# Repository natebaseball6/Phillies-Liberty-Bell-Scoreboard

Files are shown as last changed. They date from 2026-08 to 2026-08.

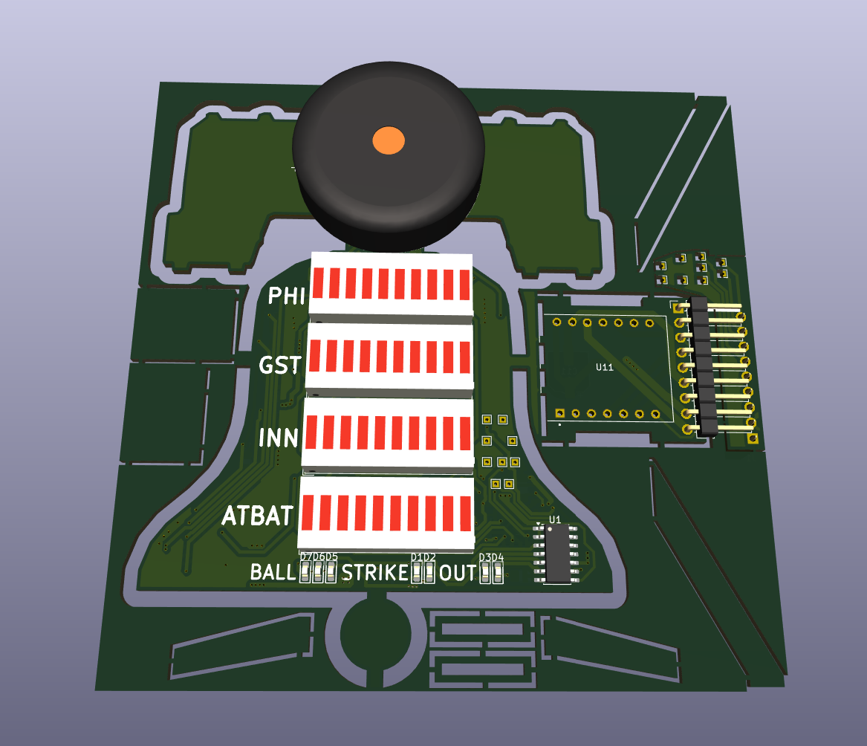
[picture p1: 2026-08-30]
Design Pictures/Screenshot 2026-08-30 145730.png

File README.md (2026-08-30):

# Phillies-Liberty-Bell-Scoreboard

Description: 

This project is intended to act as a desk toy resembling the Citizens' Bank Park Liberty Bell that "rings" whenever the Phillies hit a home run or win a game. The "bell" will feature a scoreboard on the front that accurately displays the live score, count, outs, inning, and more of a game.

The entire construction will be comprised of circuit board to minimize cost, as many small scale services such as JLC-PCB offer a fixed price for certain sizes of board, even if they are cut to smaller or more unique shapes. The shape of the bell will be one large circuit board, and the stand that holds it up will be a combination of smaller ones. 

The circuit will be ESP32 based, and overall very rudimentary and simple. Seven segment displays, individual LEDs, and a buzzer will be addressed by this ESP32.

The ESP32 will be connected to the local Wi-Fi network, and will fetch data from the MLB API for live scores.

Current Progress:

Brainstorming: DONE

Schematic Design (KiCAD): DONE

PCB Design (KiCAD): DONE

Physical Construction (JLCPCB + Digi Key): INCOMPLETE

Initial Test: INCOMPLETE

Programming: INCOMPLETE

API Test: INCOMPLETE

Polishing/Completion: INCOMPLETE

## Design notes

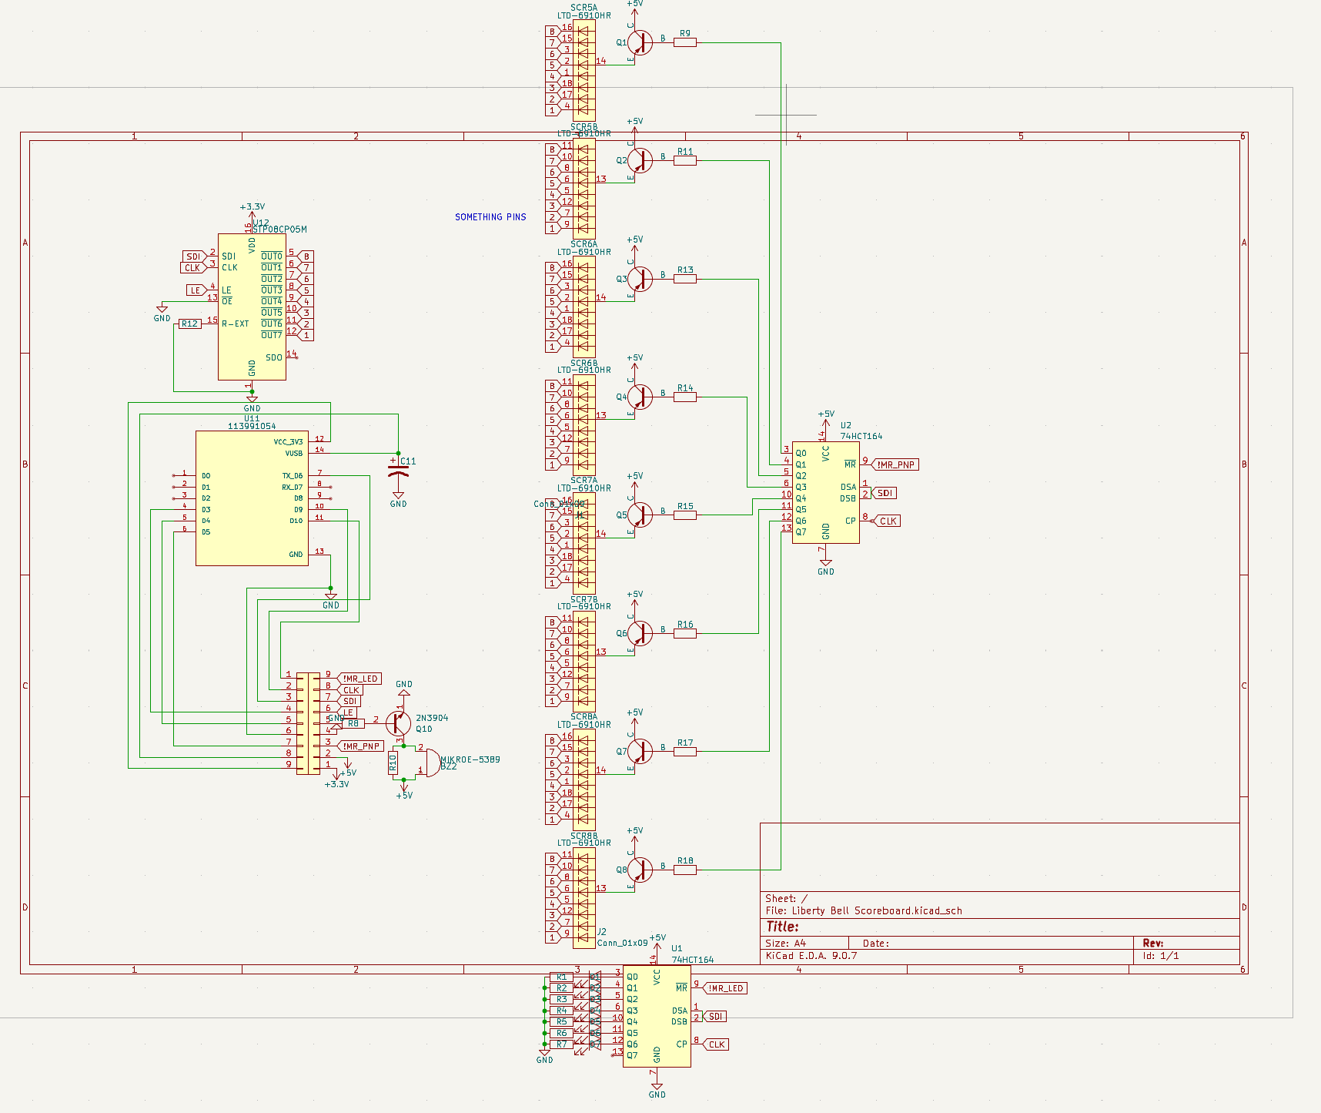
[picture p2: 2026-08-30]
Design Pictures/Screenshot 2026-08-30 145603.png

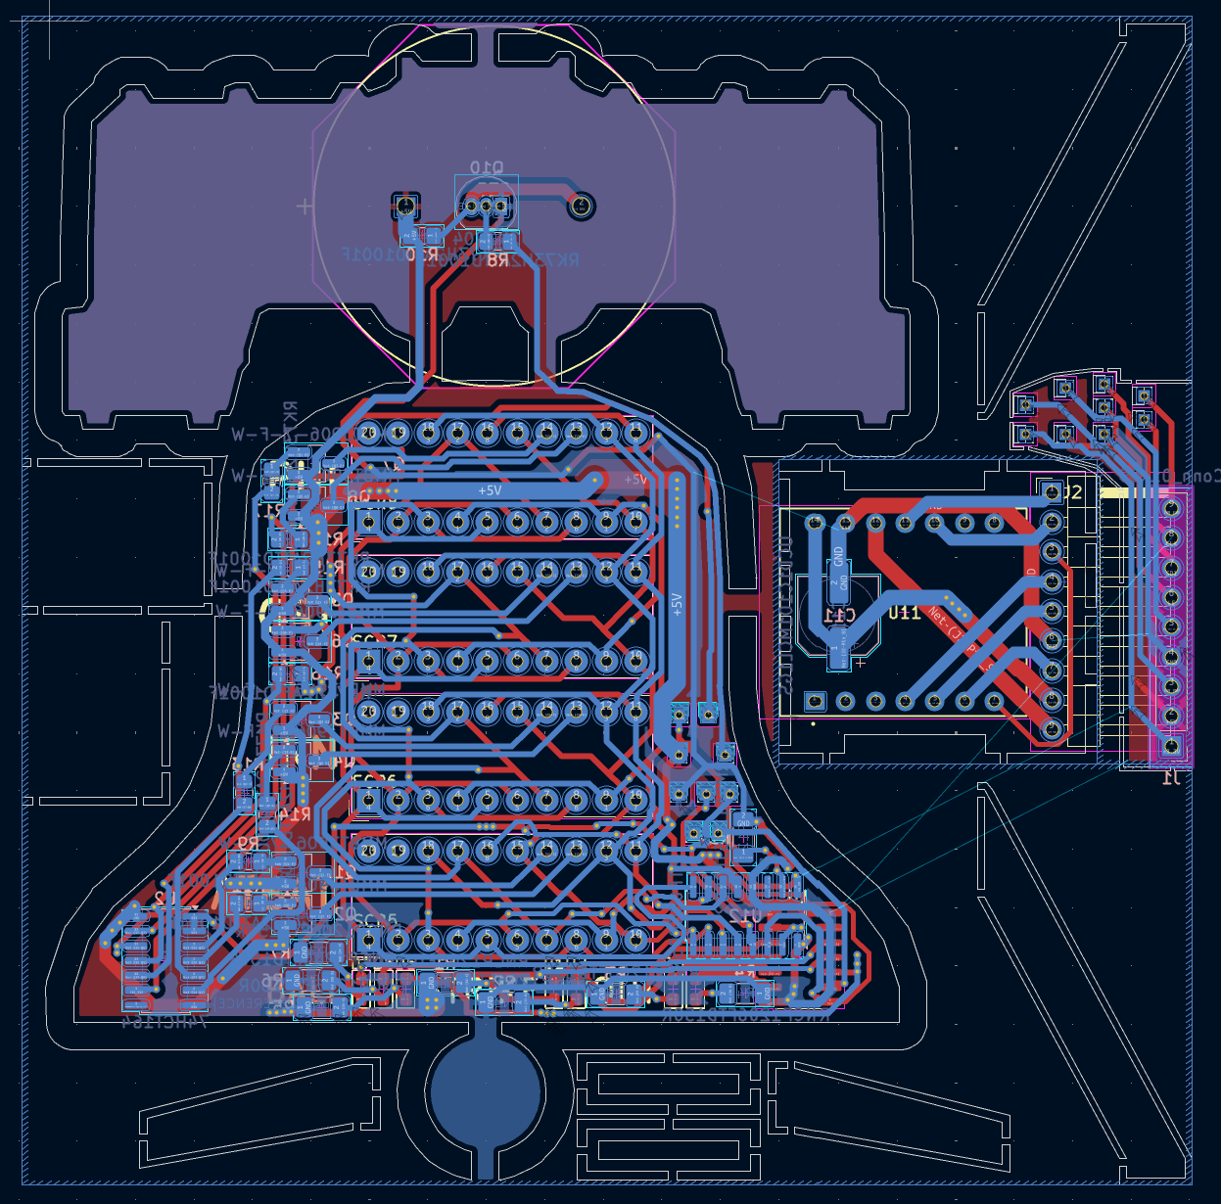
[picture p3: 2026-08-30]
Design Pictures/Screenshot 2026-08-30 145659.png

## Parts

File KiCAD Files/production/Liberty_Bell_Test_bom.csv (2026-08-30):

Designator | Footprint | Quantity | Value | LCSC Part #
BZ2 | LS_CT30P_CGE | 1 | MIKROE-5389
C11 | CP_Elec_6.3x5.9 | 1 | UCD1C101MCL1GS
D1, D2, D3, D4, D5, D6, D7 | 0603 | 7 | SML-D12U1WT86
J1 | PinSocket_1x09_P2.54mm_Vertical | 1 | Conn_01x09
J2 | PinHeader_1x09_P2.54mm_Horizontal | 1 | Conn_01x09
Q1, Q2, Q3, Q4, Q5, Q6, Q7, Q8 | SOT-23_Handsoldering | 8 | MMBT3906-7-F-W
Q10 | TO-92_Inline | 1 | 2N3904
R1, R2, R3, R4, R5, R6, R7 | 1206 | 7 | RNCP1206FTD150R
R10, R11, R13, R14, R15, R16, R17, R18, R8, R9 | 0805 | 10 | RK73H2ATTD1001F
R12 | 1206 | 1 | RMCF1206JT240R
SCR5, SCR6, SCR7, SCR8 | HDSP-4830 | 4 | LTD-6910HR
U1, U2 | SOIC-14_3.9x8.7mm_P1.27mm | 2 | 74HCT164
U11 | MODULE_113991054 | 1 | 113991054
U12 | SOIC-16_3.9x9.9mm_P1.27mm | 1 | STP08CP05M

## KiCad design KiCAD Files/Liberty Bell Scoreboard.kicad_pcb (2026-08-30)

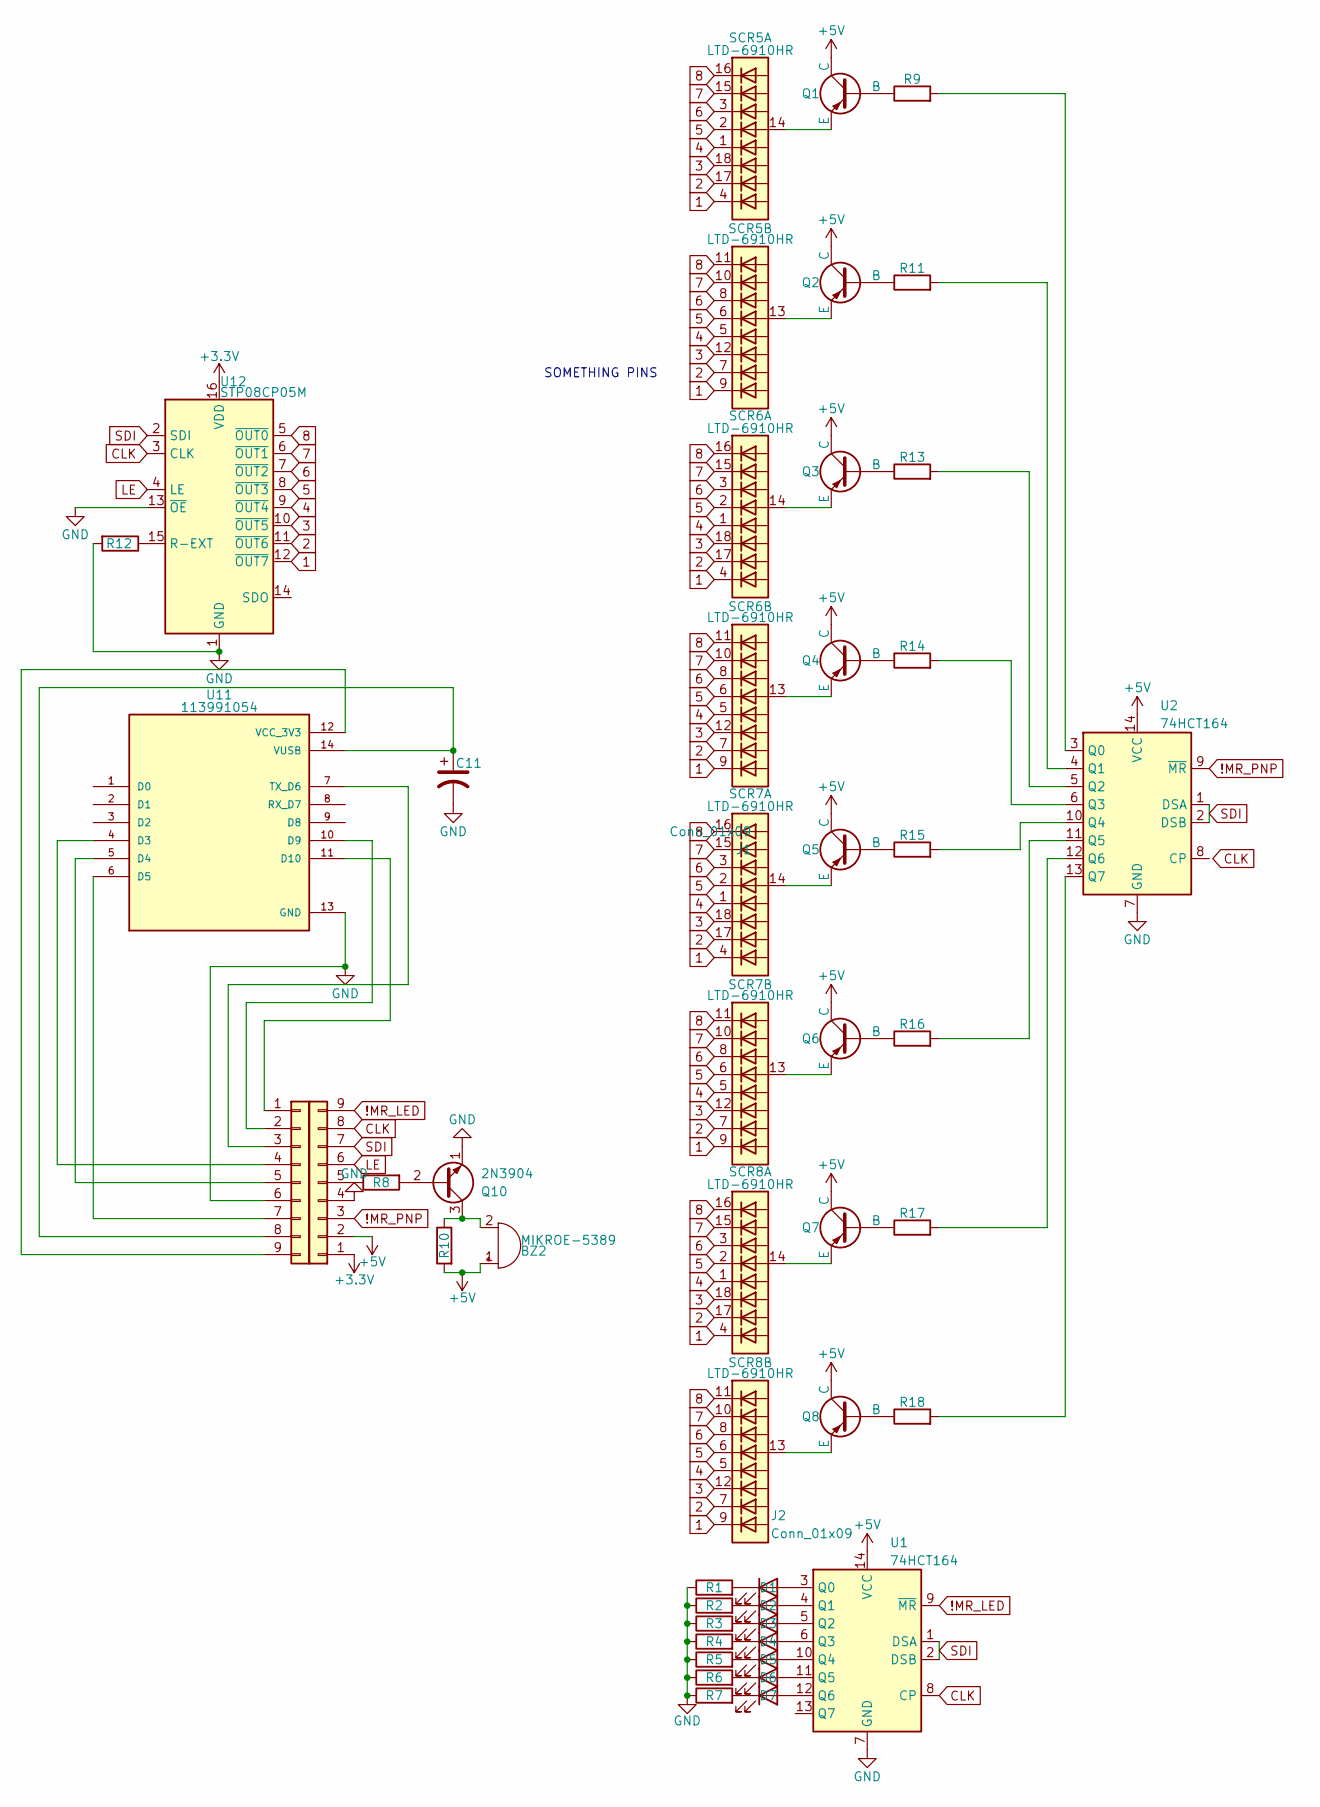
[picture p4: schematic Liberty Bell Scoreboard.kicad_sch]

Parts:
BZ2: MIKROE-5389; LS_CT30P_CGE
C11: UCD1C101MCL1GS; CP_Elec_6.3x5.9
D1, D2, D3, D4, D5, D6, D7: SML-D12U1WT86; LED_0603_1608Metric_Pad1.05x0.95mm_HandSolder
J1: Conn_01x09; PinSocket_1x09_P2.54mm_Vertical
J2: Conn_01x09; PinHeader_1x09_P2.54mm_Horizontal
Q1, Q2, Q3, Q4, Q5, Q6, Q7, Q8: MMBT3906-7-F-W; SOT-23_Handsoldering
Q10: 2N3904; TO-92_Inline
R1, R2, R3, R4, R5, R6, R7: RNCP1206FTD150R; R_1206_3216Metric_Pad1.30x1.75mm_HandSolder
R8, R9, R10, R11, R13, R14, R15, R16, R17, R18: RK73H2ATTD1001F; R_0805_2012Metric_Pad1.20x1.40mm_HandSolder
R12: RMCF1206JT240R; R_1206_3216Metric_Pad1.30x1.75mm_HandSolder
SCR5, SCR6, SCR7, SCR8: LTD-6910HR; HDSP-4830
U1, U2: 74HCT164; SOIC-14_3.9x8.7mm_P1.27mm
U11: 113991054; MODULE_113991054; PARTREV 23/05/2022; DigiKey_Part_Number 1597-113991054-ND
U12: STP08CP05M; SOIC-16_3.9x9.9mm_P1.27mm

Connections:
1: SCR5.4 (A), SCR5.9 (A), SCR6.4 (A), SCR6.9 (A), SCR7.4 (A), SCR7.9 (A), SCR8.4 (A), SCR8.9 (A), U12.12 (~OUT7)
2: SCR5.7 (A), SCR5.17 (A), SCR6.7 (A), SCR6.17 (A), SCR7.7 (A), SCR7.17 (A), SCR8.7 (A), SCR8.17 (A), U12.11 (~OUT6)
3: SCR5.12, SCR5.18 (12), SCR6.12, SCR6.18 (12), SCR7.12, SCR7.18 (12), SCR8.12, SCR8.18 (12), U12.10 (~OUT5)
4: SCR5.1 (A), SCR5.5 (A), SCR6.1 (A), SCR6.5 (A), SCR7.1 (A), SCR7.5 (A), SCR8.1 (A), SCR8.5 (A), U12.9 (~OUT4)
5: SCR5.2, SCR5.6 (A), SCR6.2, SCR6.6 (A), SCR7.2, SCR7.6 (A), SCR8.2, SCR8.6 (A), U12.8 (~OUT3)
6: SCR5.3, SCR5.8 (A), SCR6.3, SCR6.8 (A), SCR7.3, SCR7.8 (A), SCR8.3, SCR8.8 (A), U12.7 (~OUT2)
7: SCR5.10 (0), SCR5.15 (0), SCR6.10 (0), SCR6.15 (0), SCR7.10 (0), SCR7.15 (0), SCR8.10 (0), SCR8.15 (0), U12.6 (~OUT1)
8: SCR5.11 (A), SCR5.16 (A), SCR6.11 (A), SCR6.16 (A), SCR7.11 (A), SCR7.16 (A), SCR8.11 (A), SCR8.16 (A), U12.5 (~OUT0)
!MR_LED: J1.9, U1.9 (~MR)
!MR_PNP: J1.3, U2.9 (~MR)
+3.3V: J1.1, U12.16 (VDD)
+5V: BZ2.1 (+), J1.2, Q1.1 (C), Q2.1 (C), Q3.1 (C), Q4.1 (C), Q5.1 (C), Q6.1 (C), Q7.1 (C), Q8.1 (C), R10.2, U1.14 (VCC), U2.14 (VCC)
CLK: J1.8, U1.8 (CP), U12.3 (CLK)
GND: C11.2, J1.4, J2.6, Q10.1 (E), R1.1, R2.1, R3.1, R4.1, R5.1, R6.1, R7.1, R12.2, U1.7 (GND), U2.7 (GND), U11.13 (GND), U12.1 (GND), U12.13 (~OE)
LE: J1.6, U12.4 (LE)
unnamed: BZ2.2 (-), Q10.3 (C), R10.1
unnamed: D1.2 (A), U1.3 (Q0)
unnamed: D1.1 (K), R1.2
unnamed: D2.2 (A), U1.4 (Q1)
unnamed: D2.1 (K), R2.2
unnamed: D3.2 (A), U1.5 (Q2)
unnamed: D3.1 (K), R3.2
unnamed: D4.2 (A), U1.6 (Q3)
unnamed: D4.1 (K), R4.2
unnamed: D5.2 (A), U1.10 (Q4)
unnamed: D5.1 (K), R5.2
unnamed: D6.2 (A), U1.11 (Q5)
unnamed: D6.1 (K), R6.2
unnamed: D7.2 (A), U1.12 (Q6)
unnamed: D7.1 (K), R7.2
unnamed: J1.5, R8.1
unnamed: J2.1, U11.11 (D10)
unnamed: J2.2, U11.10 (D9)
unnamed: J2.3, U11.7 (TX_D6)
unnamed: J2.4, U11.4 (D3)
unnamed: J2.5, U11.5 (D4)
unnamed: J2.7, U11.6 (D5)
unnamed: C11.1, J2.8, U11.14 (VUSB)
unnamed: J2.9, U11.12 (VCC_3V3)
unnamed: Q1.2 (B), R9.1
unnamed: Q1.3 (E), SCR5.14 (DIGIT_2)
unnamed: Q2.2 (B), R11.1
unnamed: Q2.3 (E), SCR5.13 (DIGIT_2)
unnamed: Q3.2 (B), R13.1
unnamed: Q3.3 (E), SCR6.14 (DIGIT_2)
unnamed: Q4.2 (B), R14.1
unnamed: Q4.3 (E), SCR6.13 (DIGIT_2)
unnamed: Q5.2 (B), R15.1
unnamed: Q5.3 (E), SCR7.14 (DIGIT_2)
unnamed: Q6.2 (B), R16.1
unnamed: Q6.3 (E), SCR7.13 (DIGIT_2)
unnamed: Q7.2 (B), R17.1
unnamed: Q7.3 (E), SCR8.14 (DIGIT_2)
unnamed: Q8.2 (B), R18.1
unnamed: Q8.3 (E), SCR8.13 (DIGIT_2)
unnamed: Q10.2 (B), R8.2
unnamed: R9.2, U2.3 (Q0)
unnamed: R11.2, U2.4 (Q1)
unnamed: R13.2, U2.5 (Q2)
unnamed: R14.2, U2.6 (Q3)
unnamed: R15.2, U2.10 (Q4)
unnamed: R16.2, U2.11 (Q5)
unnamed: R17.2, U2.12 (Q6)
unnamed: R18.2, U2.13 (Q7)
unnamed: R12.1, U12.15 (R-EXT)
SDI: J1.7, U1.1 (DSA), U1.2 (DSB), U2.1 (DSA), U2.2 (DSB), U12.2 (SDI)

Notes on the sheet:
SOMETHING PINS

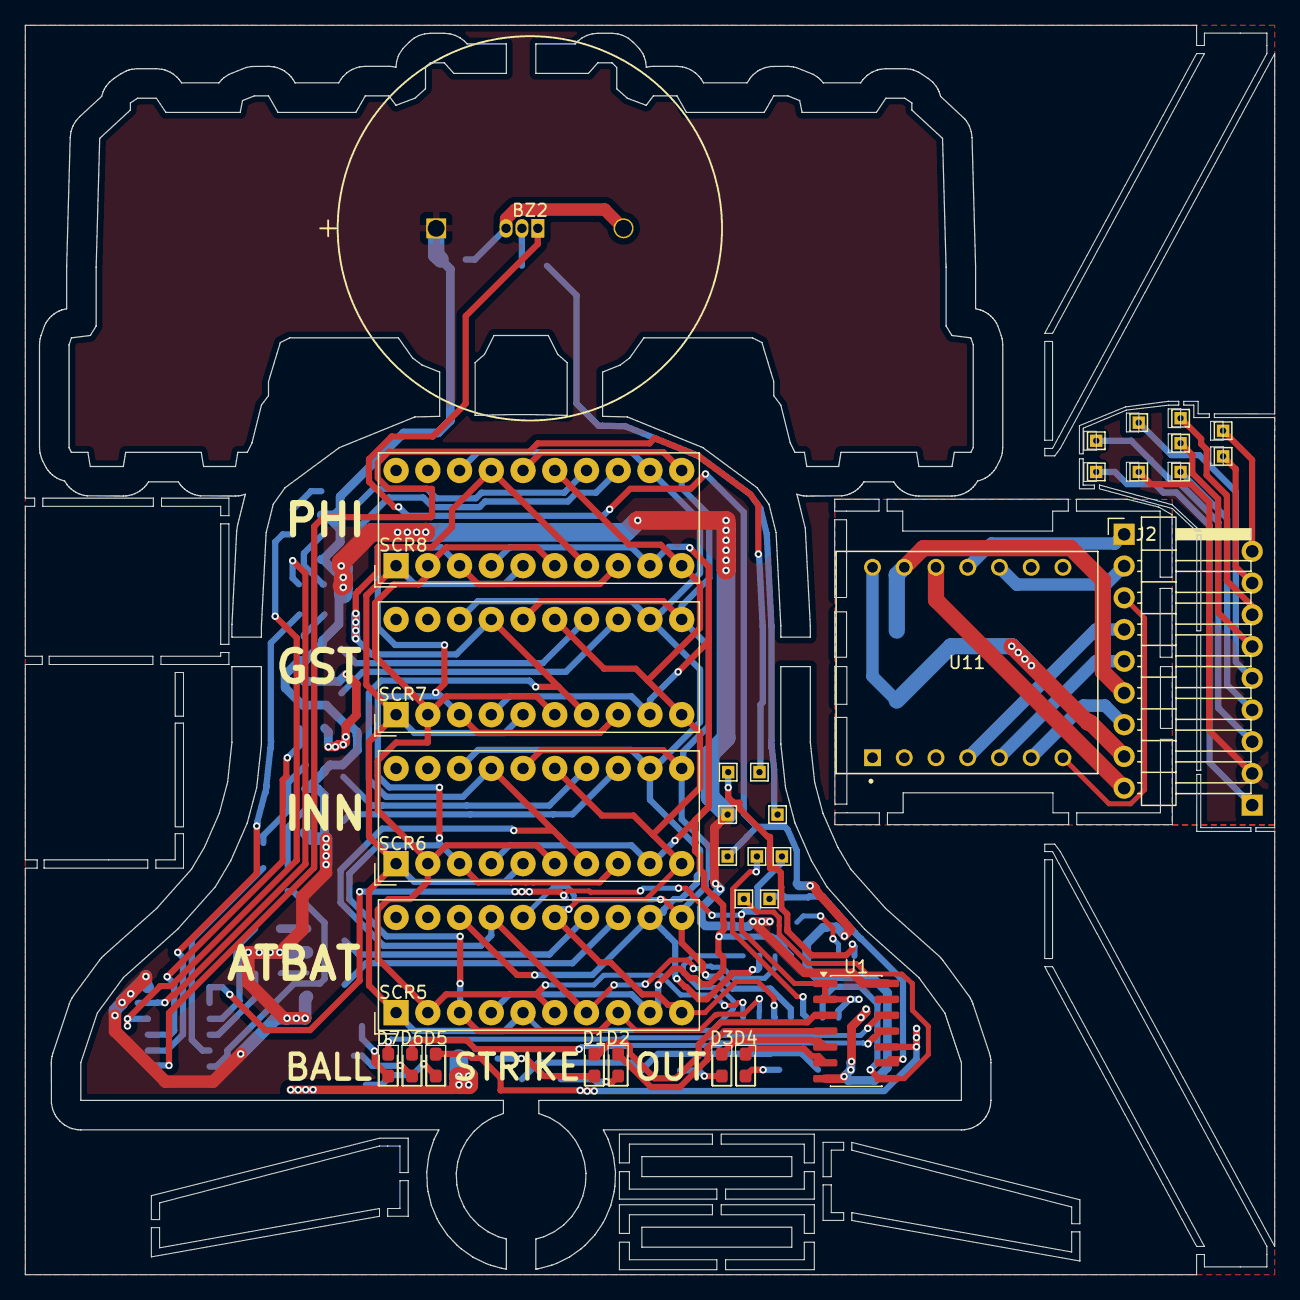
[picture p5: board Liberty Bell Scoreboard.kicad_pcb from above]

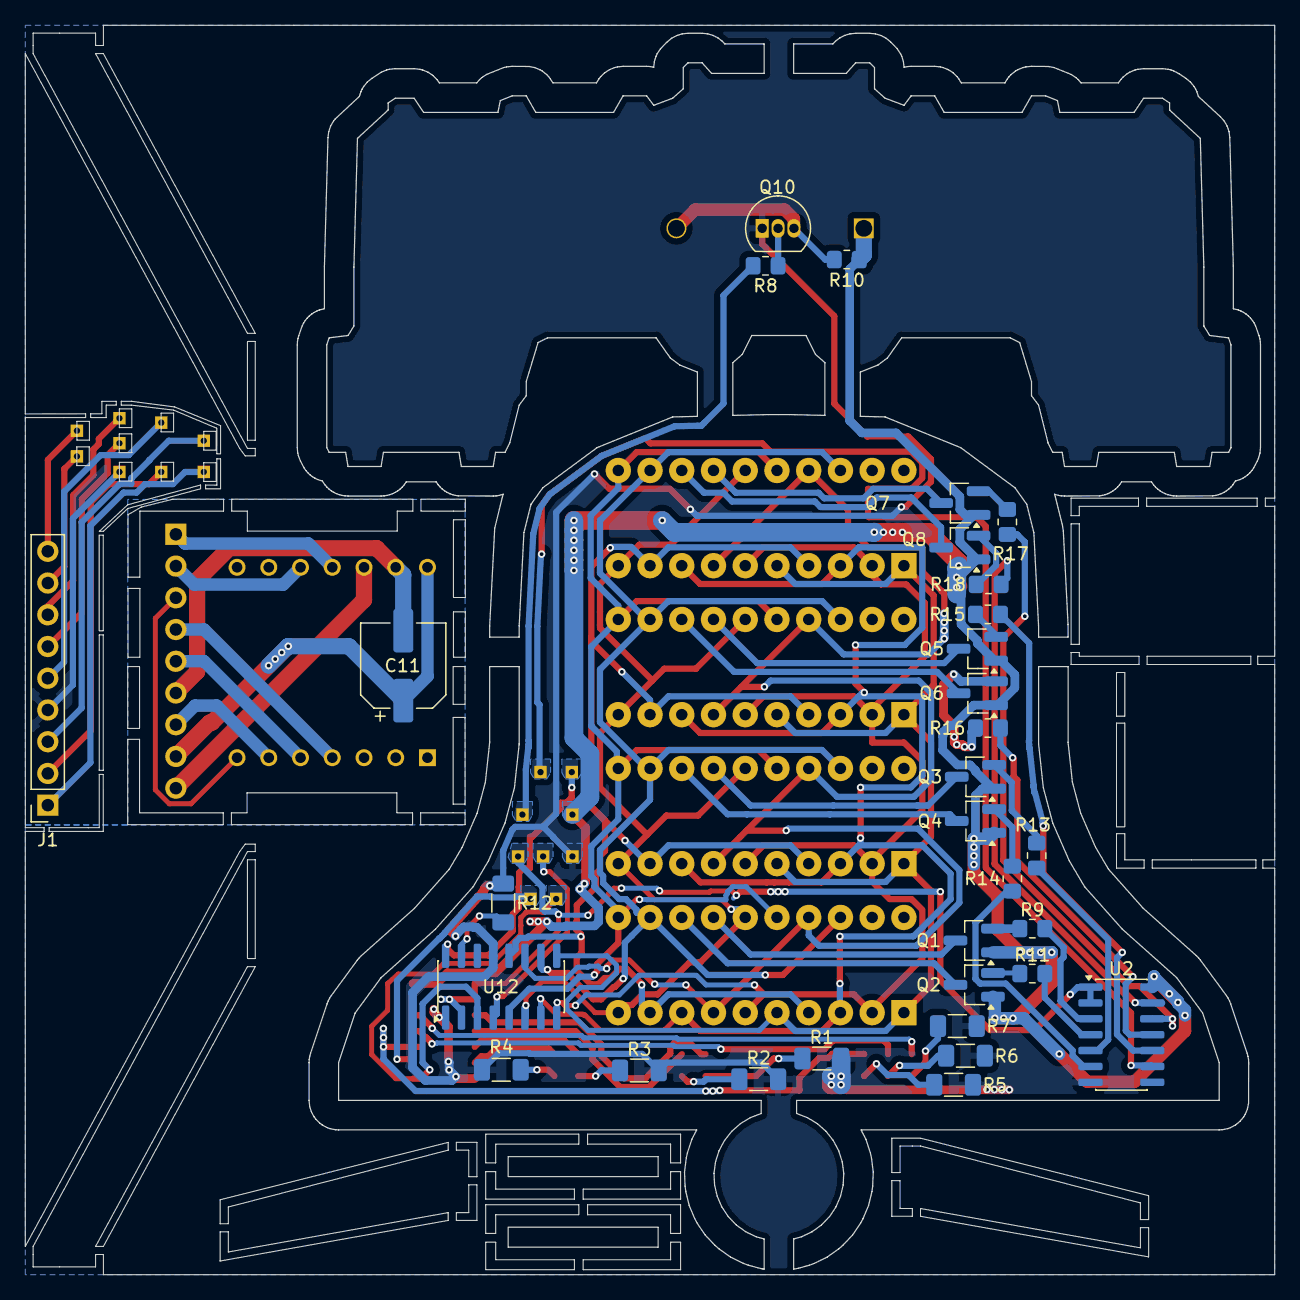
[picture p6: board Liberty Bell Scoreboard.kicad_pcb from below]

Board: 2 copper layers, 100.0 x 100.0 mm, 46 parts (31 on the bottom side), 66 nets.
